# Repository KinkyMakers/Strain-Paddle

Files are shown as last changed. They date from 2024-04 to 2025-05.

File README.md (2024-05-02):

# Strain Gauge Based Paddle

This paddle is deisgned to read the impact force via built-in PCB strain guage. Current design files are available in this repository, while functional do not represent the final working design. Errors are being corrected.

Using the smallest traces available from JLCPCB we embeded this pattern to be used as a strain guage. It its biased towards deflection in the length of the paddle.





# PCB Layout

I am happy the general concept works, and that the paddle is responsive. There are likely a few things we will find need to be improved after the first batch are out in the wild.



I'm really happy with two things on this board, the labelling - making the workshop easier. The second being the half-holes to reduce handle width, all though it was pointed out to me that quater holes may actually be possible and will reduce the width furthers. 

# Accelerometer



If we're reading the force with the strain gauge, why bother with the accelerometer? Well a) it's a backup incase those readings are better b) it was suggested that with some sensor fusion and measurments of the mass of the paddle we can get some really accurate readings on total energy transfered. I'm not the maths person, but I am all for more options!

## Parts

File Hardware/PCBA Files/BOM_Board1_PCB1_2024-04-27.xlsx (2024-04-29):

No. | Quantity | Device | Designator | Footprint | Value | Manufacturer Part | Manufacturer | Supplier Part | Supplier
1 | 3 | CC0603KRX7R9BB104 | C1,C2,C6 | C0603 | 100nF | CC0603KRX7R9BB104 | YAGEO(国巨) | C14663 | LCSC
2 | 3 | CL21A106KAYNNNE_C15850 | C3,C4,C5 | C0805 | 10uF | CL21A106KAYNNNE | SAMSUNG(三星) | C15850 | LCSC
3 | 2 | 0402X104K250CT | C9,C11 | C0402 | 100nF | 0402X104K250CT | 华新科(Walsin) | C237172 | LCSC
4 | 1 | GRM155R61E105KA12D | C10 | C0402 | 1uF | GRM155R61E105KA12D | muRata(村田) | C77009 | LCSC
5 | 4 | GRM155R61A106ME44D | C12,C13,C14,C15 | C0402 | 10uF | GRM155R61A106ME44D | muRata(村田) | C77000 | LCSC
6 | 3 | CL10A106MQ8NNNC | C16,C17,C18 | C0603 | 10uF | CL10A106MQ8NNNC | SAMSUNG(三星) | C1691 | LCSC
7 | 1 | CL10A106KP8NNNC | C19 | C0603 | 10uF | CL10A106KP8NNNC | SAMSUNG(三星) | C19702 | LCSC
8 | 1 | 0603B104K500NT_C30926 | C20 | C0603 | 100nF | 0603B104K500NT | FH(风华) | C30926 | LCSC
9 | 2 | CL31A226KAHNNNE | C21,C22 | C1206 | 22uF | CL31A226KAHNNNE | SAMSUNG(三星) | C12891 | LCSC
10 | 1 | MB10S_C2488 | D1 | MBS_L4.7-W3.8-P2.40-LS7.0-TL |  | MB10S | MDD | C2488 | LCSC
11 | 1 | FXL0530-4R7-M | L2 | IND-SMD_L5.4-W5.2_FXL0530 | 4.7uH | FXL0530-4R7-M | cjiang(长江微电) | C177246 | LCSC
12 | 1 | XL-5050RGBC-WS2812B | LED1 | LED-SMD_4P-L5.0-W5.0-BL_XL-5050RGBC |  | XL-5050RGBC-WS2812B | XINGLIGHT(成兴光) | C2843785 | LCSC
13 | 1 | BL-HJC36G-AV-TRB | LED2 | LED0603-R-RD_AMBER |  | BL-HJC36G-AV-TRB | BrtLed(佰鸿) | C165983 | LCSC
14 | 1 | NH-B1010RGBT-HF | LED3 | LED-ARRAY-SMD_4P-L1.0-W1.0-TR_NH-B1010RGBT |  | NH-B1010RGBT-HF | 国星光电 | C2874113 | LCSC
15 | 1 | S8550_C2891805 | Q1 | SOT-23-3_L2.9-W1.3-P1.90-LS2.4-BR |  | S8550 | YONGYUTAI(永裕泰) | C2891805 | LCSC
16 | 2 | BC817 | Q5,Q6 | SOT-23-3_L2.9-W1.3-P1.90-LS2.4-BR |  | BC817 | CJ（江苏长电/长晶） | C2137 | LCSC
17 | 1 | 0603WAF6651T5E | R1 | R0603 | 6.65kΩ | 0603WAF6651T5E | UNI-ROYAL(厚声) | C60344 | LCSC
18 | 1 | 0805W8F1002T5E | R2 | R0805 | 10kΩ | 0805W8F1002T5E | UNI-ROYAL(厚声) | C17414 | LCSC
19 | 4 | WR04X1002FTL | R7,R8,R13,R14 | R0402 | 10kΩ | WR04X1002FTL | 华新科(Walsin) | C163810 | LCSC
20 | 2 | AECR0402F100RK9 | R9,R10 | R0402 | 100Ω | AECR0402F100RK9 | RESI(开步睿思） | C328297 | LCSC
21 | 2 | ERJ2RKF5101X | R11,R12 | R0402 | 5.1kΩ | ERJ2RKF5101X | PANASONIC(松下) | C278598 | LCSC
22 | 1 | 0603WAF3300T5E | R15 | R0603 | 330Ω | 0603WAF3300T5E | UNI-ROYAL(厚声) | C23138 | LCSC
23 | 3 | 0603WAF1000T5E | R18,R19,R21 | R0603 | 100Ω | 0603WAF1000T5E | UNI-ROYAL(厚声) | C22775 | LCSC
24 | 1 | SK12D07VG4 | SW1 | SW-TH_SK12D07VG4 |  | SK12D07VG4 | SHOU HAN(首韩) | C393937 | LCSC
25 | 1 | 1TS003B-1400-3500A-CT | SW2 | KEY-SMD_1TS003B |  | 1TS003B-1400-3500A-CT | HYP(鸿源精密) | C319392 | LCSC
26 | 1 | LIS2DW12TR | U2 | LGA-12_L2.0-W2.0-P0.50-BL |  | LIS2DW12TR | ST(意法半导体) | C189624 | LCSC
27 | 1 | HX711 | U3 | SOP-16_L10.0-W3.9-P1.27-LS6.0-BL |  | HX711 | AVIA(海芯科技) | C43656 | LCSC
28 | 1 | CP2102-GMR | U5 | WQFN-28_L5.0-W5.0-P0.50-BL-EP3.2 |  | CP2102-GMR | SILICON LABS(芯科) | C6568 | LCSC
29 | 1 | ESP32-WROOM-32E(8MB) | U6 | WIFI-SMD_ESP32-WROOM-32E |  | ESP32-WROOM-32E(8MB) | ESPRESSIF 乐鑫 | C701342 | LCSC
30 | 1 | AMS1117-3.3_C347222 | U7 | SOT-223-4_L6.5-W3.5-P2.30-LS7.0-BR |  | AMS1117-3.3 | UMW(友台半导体) | C347222 | LCSC
31 | 1 | AP63203WU-7 | U8 | TSOT-26_L2.9-W1.6-P0.95-LS2.8-BL |  | AP63203WU-7 | DIODES(美台) | C780769 | LCSC
32 | 1 | TYPE-C-31-M-12 | USBC1 | USB-C_SMD-TYPE-C-31-M-12 |  | TYPE-C-31-M-12 | 韩国韩荣 | C165948 | LCSC

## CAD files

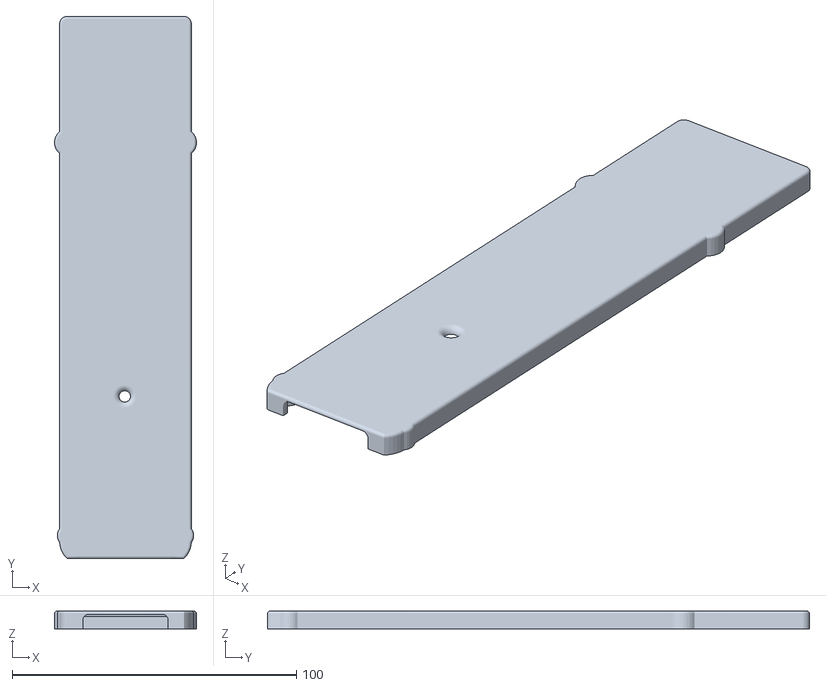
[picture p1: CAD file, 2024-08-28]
Hardware/top of handle cover.stl
50.0 x 190.8 x 6.30

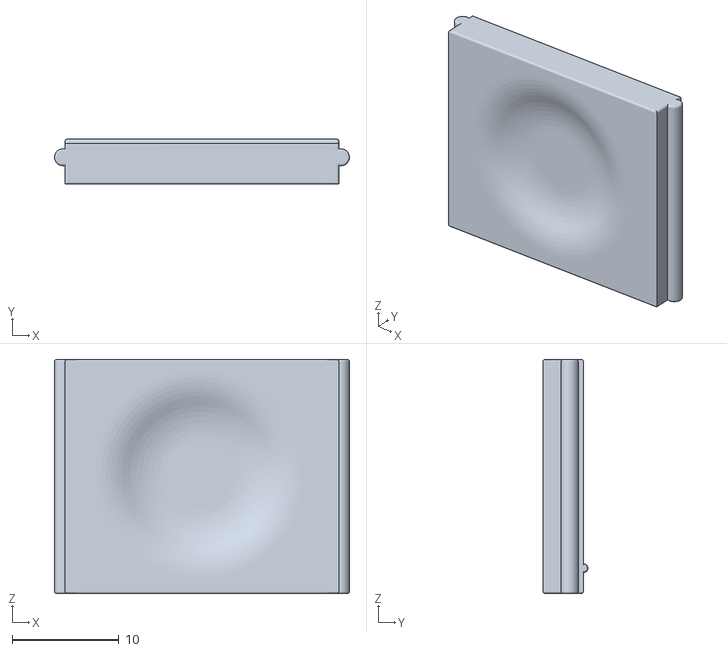
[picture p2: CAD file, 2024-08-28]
Hardware/Battery Cover.stl
27.6 x 4.21 x 21.9

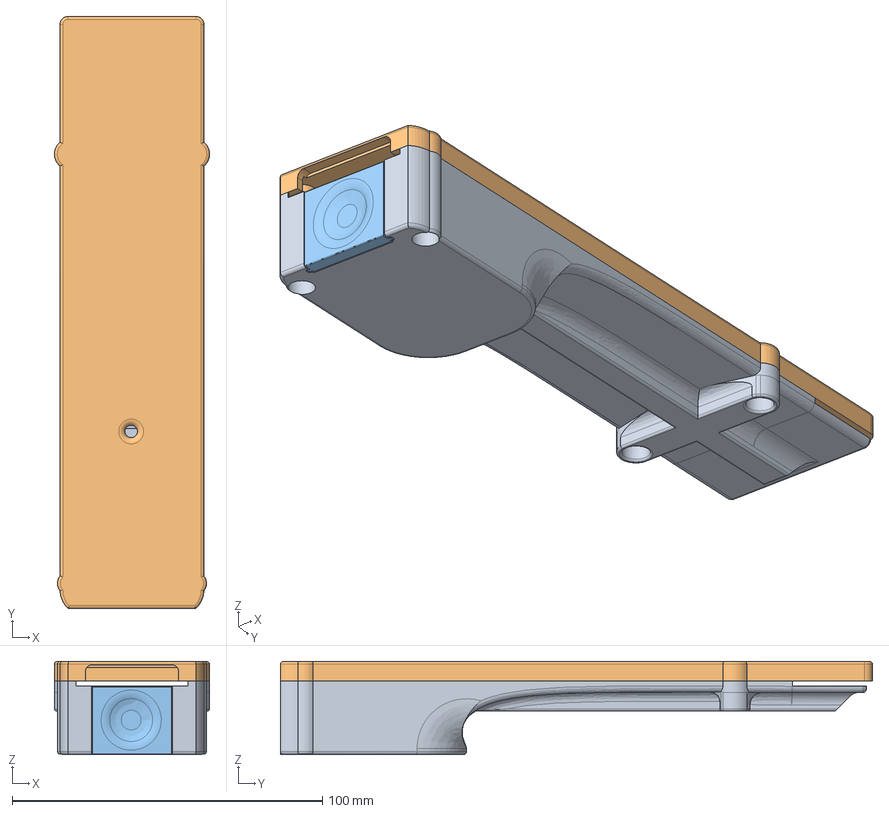
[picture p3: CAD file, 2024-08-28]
Hardware/Handle Cover.step
50.0 x 190.8 x 30.0 mm

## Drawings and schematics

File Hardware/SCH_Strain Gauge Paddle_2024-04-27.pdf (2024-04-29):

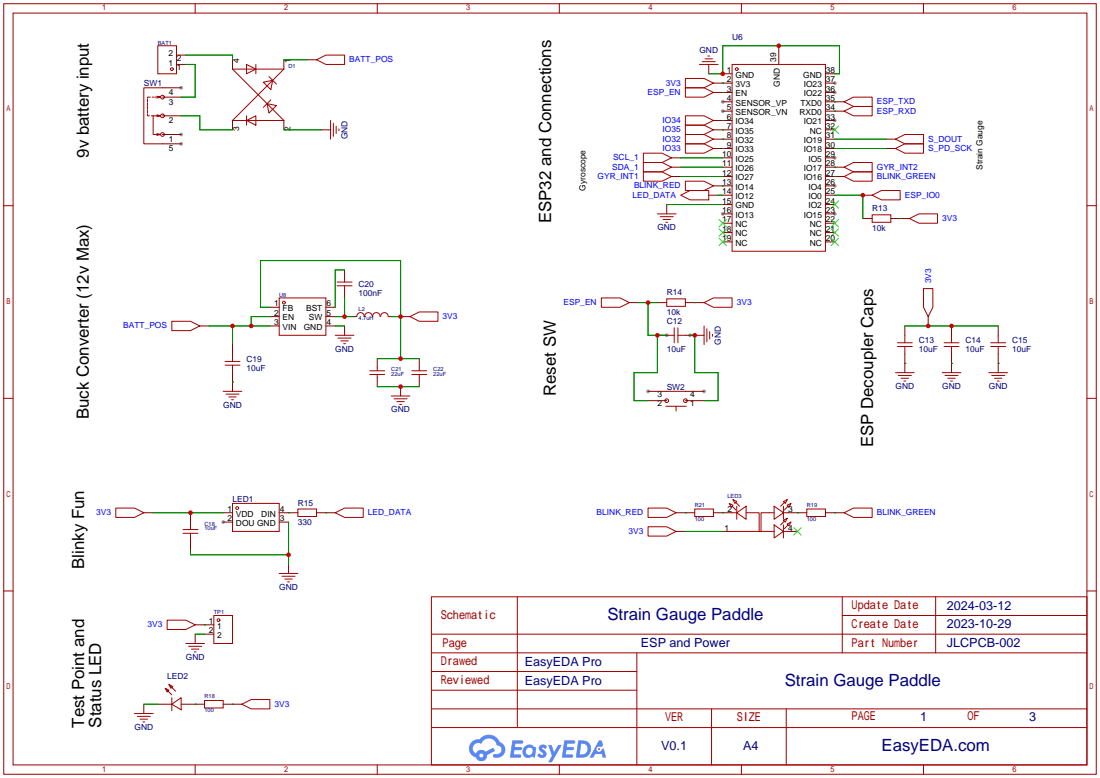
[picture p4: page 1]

9v battery input Buck Converter (12v Max) Blinky Fun

# GYR_INT1 HX⁷¹¹

# LIS2DW12TR

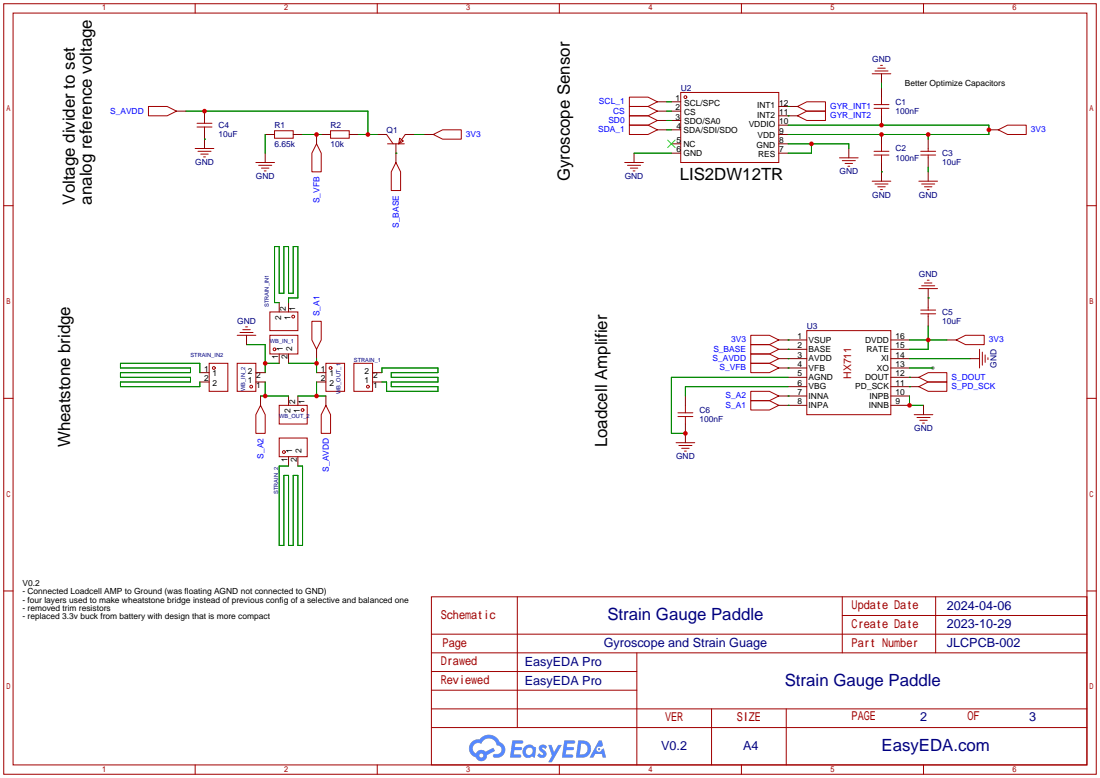
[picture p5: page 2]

Voltage divider to set

INPB 10 PD_SCK 11 DOUT 12 XO 13 XI 14 RATE 15 DVDD 16

- Connected Loadcell AMP to Ground (was floating AGND not connected to GND)
- four layers used to make wheatstone bridge instead of previous config of a selective and balanced one
- removed trim resistors
- replaced 3.3v buck from battery with design that is more compact

2023-10-29 Strain Gauge Paddle
Gyroscope and Strain Guage

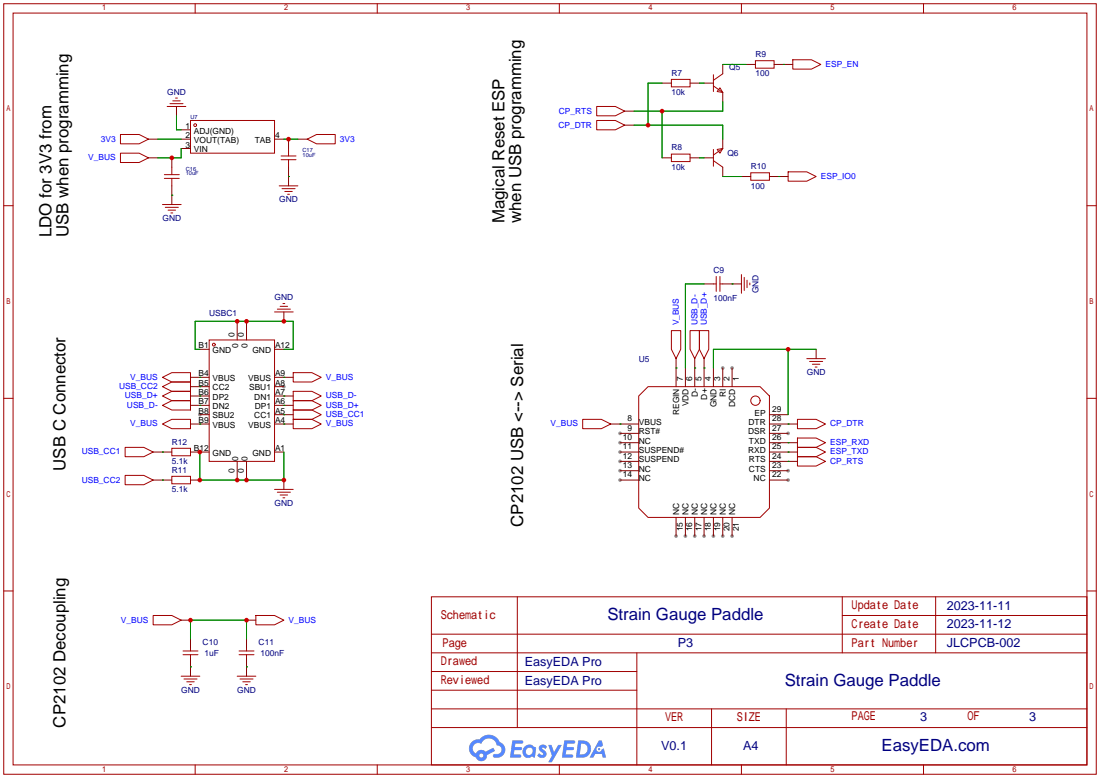
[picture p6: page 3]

GND
NC 22 CTS 23 RTS 24 RXD 25 TXD 26 DSR 27 DTR 28 EP 29

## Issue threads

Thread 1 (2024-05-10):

Files for 3d printed handle

Drc3p0, 2024-05-10:
Hi! Do you have the files for the 3d printed handle you could share? I wanted to redesign mine to be more ergonomic and clear/translucent so you can peek the insides more easily. Thanks!

riggingdelight, 2024-08-28:
uploaded the files, hope that is everything need. Please if you find a more ergonomic shape, share it back and I'll make it the default.

Closed 2024-08-28.

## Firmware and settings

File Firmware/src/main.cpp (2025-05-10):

//   _________ __                .__      __________             .___  .___.__          
//  /   _____//  |_____________  |__| ____\______   \_____     __| _/__| _/|  |   ____  
//  \_____  \\   __\_  __ \__  \ |  |/    \|     ___/\__  \   / __ |/ __ | |  | _/ __ \ 
//  /        \|  |  |  | \// __ \|  |   |  \    |     / __ \_/ /_/ / /_/ | |  |_\  ___/ 
// /_______  /|__|  |__|  (____  /__|___|  /____|    (____  /\____ \____ | |____/\___  >
//         \/                  \/        \/               \/      \/    \/      2024 \/ 
//
//  By: KinkMakers.core()
//  Version 1.0
//
//  See Licenses.txt file for details of included items

#include "def.h"      // pin definitions and helpers
#include <Arduino.h>  // Arduino library, some functions just make it easier to have this included
#include <FastLED.h>  // LED library
#include <HX711.h>    // load cell library
#include <Wire.h>     // I2C library
#include <EEPROM.h>   // include for reading/write to eeprom
#include <esp_now.h>  // include for esp now
#include <WiFi.h>     // include for wifi
#include <CircularBuffer.h> // include for circular buffer

/////////////////////////////////////////////
// Setup Your Device here
/////////////////////////////////////////////

#define MyDeviceName "James 'Fucking' Holden"                 // Name of the device
#define autoStart true                 // Start the serial dump automatically
#define CALIBRATION_FACTOR_ADDRESS 0    // Address in EEPROM to store the calibration factor

CRGB leds[1]; //LED strip object
HX711 scale;  //load cell object

int calibration_factor = 250; //calibration factor for load cell 
bool run = false;             // run will be flagged in Setup() after the first tare if autoStart is true
long espNowSendTime = 0;      // time to send the next ESP_NOW message
long peakTime = 0;            // time to reset the peak value
float current_reading = 0;

/////////////////////////////////////////////
// After Now Function
/////////////////////////////////////////////

// if the current time in millis() is greater than the input return true
bool afterNow(unsigned long time){
  return millis() > time;
}

/////////////////////////////////////////////
// ESP NOW
/////////////////////////////////////////////

  uint8_t broadcastAddress[] = {0xFF, 0xFF, 0xFF, 0xFF, 0xFF, 0xFF}; // using broadcast address to send the data to all peers

  // Data Structure to send data
  typedef struct struct_message {
    float peakValue;
    uint8_t macAddress[6];
    char deviceName[20];
  } struct_message;
  
  typedef struct sex_struct {
    int passcode;
    char data_name[20];
    float data;
    char data_unit[10];
  } sex_struct;

  // Create a struct_message called myData
  sex_struct myData;
  esp_now_peer_info_t peerInfo;

  // callback when data is sent
  void OnDataSent(const uint8_t *mac_addr, esp_now_send_status_t status) {
    // only log the send status if it failed
    if (status != ESP_NOW_SEND_SUCCESS) {
      LogError("Last Packet Send Status:\t" + String(status == ESP_NOW_SEND_SUCCESS ? "Delivery Success" : "Delivery Fail"));
    }
  }

/////////////////////////////////////////////////
// Load Cell Functions
/////////////////////////////////////////////////

float readLoadCell() {
  float load = scale.get_units(5); // Get average of 5 readings
  return load;
}

void led_from_strain(float strain)
  {

    //the LED will change color based on the load cell reading
    //if the load cell is greater than 1, the LED will be red
    //if the load cell is less than 1, the LED will be green fading to yellow to red
    if(strain > 1){
        leds[0] = CRGB::Red;
        FastLED.show();
        }
      else
      {
        leds[0] = CHSV(85 - strain * 85, 255, 255);
        FastLED.show();
        };

  }

  /////////////////////////////////////////////////
  // PEAK DETECTION
  /////////////////////////////////////////////////

  float lastPEAK = 0.0; // Global variable to store the last peak
  unsigned long lastPeakTime = 0; // Time when the last peak was detected
  const unsigned long PEAK_HOLD_TIME = 6000; // Hold peak for 5 seconds
  const int maxReadings = 20; // Maximum number of readings for noise floor calculation
  CircularBuffer<float, maxReadings> readings; // Circular buffer to store recent readings
  float lastReading = 0.0; // Store the last reading for trend detection

  // High-pass filter variables
  float alpha = 0.3; // Filter coefficient (0.0 to 1.0)
  float lastFilteredValue = 0.0; // Last filtered value
  float lastRawValue = 0.0; // Last raw value

// Function to apply high-pass filter
float highPassFilter(float input) {
    // First order high-pass filter
    float filtered = alpha * (lastFilteredValue + input - lastRawValue);
    lastFilteredValue = filtered;
    lastRawValue = input;
    return filtered;
}

// Function to calculate the average of the readings array
float calculateAverage() {
    float sum = 0.0;
    int count = readings.size();
    for (int i = 0; i < count; i++) {
        sum += readings[i];
    }
    return count > 0 ? sum / count : 0.0;
}

// Function to update the last peak value
void updateLastPeak(float currentReading) {
    // Add reading to the circular buffer
    readings.push(currentReading);

    // Calculate noise floor as the average of recent readings
    float noiseFloor = calculateAverage();

    // Set a dynamic threshold, adjust the multiplier as needed
    float dynamicThreshold = noiseFloor * 1.1; // 10% above the noise floor

    // Check if current reading is a peak
    if (currentReading > dynamicThreshold) {
        // Detect if we're at a peak by checking if the current reading is higher than the last
        // and if we're above the threshold
        if (currentReading > lastReading && currentReading > lastPEAK) {
            lastPEAK = currentReading;
            lastPeakTime = millis();
        }
    }

    // Store current reading for next comparison
    lastReading = currentReading;

    // Reset peak if it's older than PEAK_HOLD_TIME
    if (millis() - lastPeakTime > PEAK_HOLD_TIME) {
        lastPEAK = 0.0;
    }
}

/////////////////////////////////////////////
// i2c Scanner
/////////////////////////////////////////////

void i2c_scanner() {
  byte error, address;
  int nDevices;

  LogDebug("Scanning for I2C devices...");

  nDevices = 0;
  for (address = 1; address < 127; address++) {
    Wire.beginTransmission(address);
    error = Wire.endTransmission();

    if (error == 0) {
      LogDebug("I2C device found at address 0x");
      if (address < 16) {
        Serial.print("0");
      }
      Serial.print(address, HEX);
      Serial.println(" !");
      nDevices++;
    }
    else if (error == 4) {
      LogError("Unknown error at address 0x");
      if (address < 16) {
        Serial.print("0");
      }
      Serial.println(address, HEX);
    }
  }
  if (nDevices == 0) {
    LogError("No I2C devices found.");
  } else {
    LogDebug("Scanning complete.");
  }
}

/////////////////////////////////////////////
// read from accelerometer
/////////////////////////////////////////////

void readAccelData(int16_t *x, int16_t *y, int16_t *z) {
  // Read STATUS register to check for data ready
  Wire.beginTransmission(g_ADDR);
  Wire.write(0x27); // STATUS register
  if (Wire.endTransmission() != 0 || Wire.requestFrom(g_ADDR, 1) != 1) {
    Serial.println("Error reading STATUS register.");
    return;
  }

  byte status = Wire.read();
  
  if (!(status & 0x01)) { // Check if DRDY (data-ready) bit is set
    Serial.println("Data not ready.");
    return;
  }
  
  // If DRDY bit is set, read accelerometer data
  Wire.beginTransmission(g_ADDR);
  Wire.write(0x28 | 0x80); // Set auto-increment and start at OUT_X_L
  if (Wire.endTransmission(false) != 0) {
    Serial.println("Error setting auto-increment address.");
    return;
  }

  Wire.requestFrom(g_ADDR, (uint8_t)6); 
  while (Wire.available() < 6);
  
  *x = Wire.read() | ((int16_t)Wire.read() << 8);
  *y = Wire.read() | ((int16_t)Wire.read() << 8);
  *z = Wire.read() | ((int16_t)Wire.read() << 8);

}

void setupAccelerometer() {
  Wire.beginTransmission(g_ADDR);
  Wire.write(0x20); // CTRL1 register address
  // Assuming you want high-performance mode at 100 Hz:
  Wire.write(0b01010100); // This is 0x4A in hexadecimal
  Wire.endTransmission();
}

void readStatusRegister() {
  Wire.beginTransmission(g_ADDR);
  Wire.write(0x27);                               // STATUS register address
  if (Wire.endTransmission() != 0) {
    Serial.println("Error transmitting to device.");
    return;
  }
  
  Wire.requestFrom(g_ADDR, 1);
  if (Wire.available()) {
    byte status = Wire.read();
    Serial.println("STATUS Register:");
    Serial.print("FIFO threshold status: ");
    Serial.println((status & 0x80) ? "FIFO above threshold" : "FIFO below threshold");
    Serial.print("Wakeup event detected: ");
    Serial.println((status & 0x40) ? "Yes" : "No");
    Serial.print("Sleep event detected: ");
    Serial.println((status & 0x20) ? "Yes" : "No");
    Serial.print("Double-tap event detected: ");
    Serial.println((status & 0x10) ? "Yes" : "No");
    Serial.print("Single-tap event detected: ");
    Serial.println((status & 0x08) ? "Yes" : "No");
    Serial.print("6D orientation change detected: ");
    Serial.println((status & 0x04) ? "Yes" : "No");
    Serial.print("Free-fall event detected: ");
    Serial.println((status & 0x02) ? "Yes" : "No");
    Serial.print("Data-ready for X, Y, and Z: ");
    Serial.println((status & 0x01) ? "Ready" : "Not ready");
  } else {
    Serial.println("No data received from STATUS register.");
  }
}

/////////////////////////////////////////////
// Loading Serial Logo for Project
/////////////////////////////////////////////

void serialLogo(){
  Serial.println(" ");
  Serial.println(" ");
  Serial.println("  _________ __                .__      __________             .___  .___.__          ");
  Serial.println(" /   _____//  |_____________  |__| ____\\______   \\_____     __| _/__| _/|  |   ____  ");
  Serial.println(" \\_____  \\\\   __\\_  __ \\__  \\ |  |/    \\|     ___/\\__  \\   / __ |/ __ | |  | _/ __ \\ ");
  Serial.println(" /        \\|  |  |  | \\// __ \\|  |   |  \\    |     / __ \\_/ /_/ / /_/ | |  |_\\  ___/ ");
  Serial.println("/_______  /|__|  |__|  (____  /__|___|  /____|    (____  /\\____ \\____ | |____/\\___  >");
  Serial.println("        \\/                  \\/        \\/               \\/      \\/    \\/      2024 \\/ ");
  Serial.println(" ");
  Serial.println(" By: KinkMakers.core()");
  Serial.println(" Version 1.0");
  Serial.println(" ");
  Serial.println(" See Licenses.txt file for details of included items");
  Serial.println(" ");
  Serial.println(" ");
}

/////////////////////////////////////////////
// Serial Response
/////////////////////////////////////////////
void serialResponse(){
      char temp = Serial.read();
    switch(temp)
    {
      case 't':
        LogStatus("Tare");
        scale.tare();
        break;
      case 'c':
        LogStatus("Calibration Factor: " + String(calibration_factor));
        break;
      case 'r':
        LogDebug("Run: " + String(run));
        run = !run;
        break;
      case 'a':
        LogStatus("Increase Calibration Factor");
        calibration_factor += 1;
        //write the calibration factor to eeprom
        EEPROM.write(CALIBRATION_FACTOR_ADDRESS, calibration_factor);
        EEPROM.commit();
        break;
      case 'z':
        LogStatus("Decrease Calibration Factor");
        calibration_factor -= 1;
        //write the calibration factor to eeprom
        EEPROM.write(CALIBRATION_FACTOR_ADDRESS, calibration_factor);
        EEPROM.commit();
        break;
      case 's':
        LogStatus("Read Status Register");
        readStatusRegister();
        break;


    } // switch(temp) 
}

/////////////////////////////////////////////
// Setup
/////////////////////////////////////////////

void setup() {

  // so the hx711 doesn't like the ESP32 at full speed, we need to slow it down
    setCpuFrequencyMhz(80); //set the CPU frequency to 80MHz

  //initialize serial monitor
    Serial.begin(115200);
    serialLogo();

  //setup the eeprom
    EEPROM.begin(512);
  
  // i2c stuff for accelerometer

    Wire.begin(g_SDA, g_SCL); // Initialize I2C with custom SDA and SCL pins
    i2c_scanner(); // Call the I2C scanner function
    setupAccelerometer();


  //read the calibration factor from eeprom
    calibration_factor = EEPROM.read(CALIBRATION_FACTOR_ADDRESS);

  //if calibration factor is 0, set it to 25, 0 =  empty EEPROM
    if(calibration_factor == 0)
    {
      calibration_factor = 25;
      EEPROM.write(CALIBRATION_FACTOR_ADDRESS, calibration_factor);
    }

  //initialize LED strip
    FastLED.addLeds<WS2812B, led_pixel, GRB>(leds, 1);
    FastLED.setBrightness(15);
    FastLED.clear();
    leds[0] = CRGB::Red;
    FastLED.show();


  //initialize the hx711

    scale.begin(s_dout, s_clock);
    scale.set_gain(64);

    delay(500);

    scale.tare();
    LogDebug("Scale tared, test reading: " + String(scale.get_units()));

    delay(500);

    LogDebug("HX711 initialized");

    long zero_factor = scale.read_average(10); //get the zero factor
      LogDebug("Zero factor: " + String(zero_factor));

  // run flag
    run = autoStart;  // Look in the defines at the top of the file to set this


  // get that LED showing something 
    FastLED.clear();
    leds[0] = CRGB::Yellow;
    FastLED.show();


  // ESPnow setup
    WiFi.mode(WIFI_STA);
    LogDebug("ESP-Now address: " + WiFi.macAddress());

    if (esp_now_init() != ESP_OK) {
      LogError("Error initializing ESP-NOW");
      return;
    } else {
      LogDebug("ESP-NOW initialized");
    }

    esp_now_register_send_cb(OnDataSent);
      LogDebug("Registering ESP-NOW send callback");


  // Register peer
    memcpy(peerInfo.peer_addr, broadcastAddress, 6);
    peerInfo.channel = 0;  
    peerInfo.encrypt = false;
  
  // Add peer        
    if (esp_now_add_peer(&peerInfo) != ESP_OK){
      LogError("Failed to add peer");
      return;
    }
    LogDebug("ESP-NOW setup complete");

    FastLED.clear();
    leds[0] = CRGB::Green;
    FastLED.show();

} //Void Setup

void loop() {

  if(run){

    //read the load cell and accelerometer
    float raw_reading = (abs(scale.get_units(2))/calibration_factor);
    current_reading = highPassFilter(raw_reading); // Apply high-pass filter to all readings
    updateLastPeak(current_reading);
    
    Serial.print(">Strain Guage:");
    Serial.println(current_reading);
    Serial.print(">Peak:");
    Serial.println(lastPEAK);

    // read from the accelerometer  
    int16_t x, y, z;
    // readAccelData(&x, &y, &z);
    // Serial.print(">X: ");
    // Serial.println(x);
    // Serial.print(">Y: ");
    // Serial.println(y);
    // Serial.print(">Z: ");
    // Serial.println(z);

    //change the LED color based on the load cell reading
    //led_from_strain(current_reading);

    // advance colour rainbow on led strip to demonstrait program is stillrunning
    static uint8_t hue = 0;
    hue++;
    leds[0] = CHSV(hue, 255, 255);
    FastLED.show();

  } // if(run)


  // Before we go check for serial input and then deal with it
  if(Serial.available()){ serialResponse();}





  if(afterNow(espNowSendTime)){
    // Send every 250ms + a random amount of time to avoid collisions
    espNowSendTime = millis() + 3000;

    // build the ESP_NOW message 
    myData.passcode = 2024;  // Direct assignment for int
    strncpy(myData.data_name, "Strain", sizeof(myData.data_name) - 1);  // Safe string copy
    myData.data = lastPEAK;  // Direct assignment for float
    // myData.data = current_reading;  // Direct assignment for float
    strncpy(myData.data_unit, "Hurt (Newtons)", sizeof(myData.data_unit) - 1);  // Safe string copy

    // Send message via ESP-NOW
    esp_err_t result = esp_now_send(broadcastAddress, (uint8_t *) &myData, sizeof(myData));
    if (result == ESP_OK) {
      // LogDebug("Sent data via ESP-NOW");
    } else {
      LogError("Error sending data via ESP-NOW");
    }
  }// if(afterNow(espNowSendTime))




} //Void Loop

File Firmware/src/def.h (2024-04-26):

//Pin Definitions

#define led_pixel 12        //ws2812b data pin
#define led_red 4           //red led pin
#define led_green 16        //green led pin

#define s_dout 19             //HX711 data pin
#define s_clock 18              //HX711 clock pin

#define g_SCL 25            //gyro scl pin
#define g_SDA 26            //gyro sda pin
#define g_INT 27            //gyro interrupt pin
#define g_INT2 17           //gyro interrupt pin 2
#define g_ADDR 0x19         //gyro i2c address


//Kyle's Macros from OSSM + some updates
#define LogDebug(message) Serial.println("[DEBUG] " + String(message))
#define LogError(message) Serial.println("[ERROR] " + String(message))
#define LogStatus(message) Serial.println("[STATUS] " + String(message))
#define LogSystem(message) Serial.println("[SYSTEM] " + String(message))

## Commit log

2023-12-18 Original Commit
    [SGP - BOM.xlsx, SGP - PNP.xlsx]
2024-01-29 updated firmware - still in alpha
    [SGP - BOM.xlsx, SGP - PNP.xlsx]
2024-04-29 update of hardware files
    [BOM_Board1_PCB1_2024-04-27.xlsx, PickAndPlace_PCB1_2024-04-27.xlsx, SGP - BOM.xlsx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]
2024-08-28 Add files via upload
    Handle Step files
    [Handle Cover.step]
2024-08-28 Add files via upload
    added STL files for printed parts
    [Battery Cover.stl, top of handle cover.stl]
2025-05-10 improved filtering
    added high pas, latches peak for 7 seconds, output every 5s
